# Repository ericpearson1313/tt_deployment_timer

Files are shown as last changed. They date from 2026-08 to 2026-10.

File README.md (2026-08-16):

   

# Tiny Tapeout Verilog Project Template

- [Read the documentation for project](docs/info.md)

## What is Tiny Tapeout?

Tiny Tapeout is an educational project that aims to make it easier and cheaper than ever to get your digital and analog designs manufactured on a real chip.

To learn more and get started, visit https://tinytapeout.com.

## Set up your Verilog project

1. Add your Verilog files to the `src` folder.
2. Edit the [info.yaml](info.yaml) and update information about your project, paying special attention to the `source_files` and `top_module` properties. If you are upgrading an existing Tiny Tapeout project, check out our [online info.yaml migration tool](https://tinytapeout.github.io/tt-yaml-upgrade-tool/).
3. Edit [docs/info.md](docs/info.md) and add a description of your project.
4. Adapt the testbench to your design. See [test/README.md](test/README.md) for more information.

The GitHub action will automatically build the ASIC files using [LibreLane](https://www.zerotoasiccourse.com/terminology/librelane/).

## Enable GitHub actions to build the results page

- [Enabling GitHub Pages](https://tinytapeout.com/faq/#my-github-action-is-failing-on-the-pages-part)

## Resources

- [FAQ](https://tinytapeout.com/faq/)
- [Digital design lessons](https://tinytapeout.com/digital_design/)
- [Learn how semiconductors work](https://tinytapeout.com/siliwiz/)
- [Join the community](https://tinytapeout.com/discord)
- [Build your design locally](https://www.tinytapeout.com/guides/local-hardening/)

## What next?

- [Submit your design to the next shuttle](https://app.tinytapeout.com/).
- Edit [this README](README.md) and explain your design, how it works, and how to test it.
- Share your project on your social network of choice:
  - LinkedIn [#tinytapeout](https://www.linkedin.com/search/results/content/?keywords=%23tinytapeout) [@TinyTapeout](https://www.linkedin.com/company/100708654/)
  - Mastodon [#tinytapeout](https://chaos.social/tags/tinytapeout) [@matthewvenn](https://chaos.social/@matthewvenn)
  - X (formerly Twitter) [#tinytapeout](https://twitter.com/hashtag/tinytapeout) [@tinytapeout](https://twitter.com/tinytapeout)
  - Bluesky [@tinytapeout.com](https://bsky.app/profile/tinytapeout.com)

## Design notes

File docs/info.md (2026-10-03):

<!---

This file is used to generate your project datasheet. Please fill in the information below and delete any unused
sections.

You can also include images in this folder and reference them in the markdown. Each image must be less than
512 kb in size, and the combined size of all images must be less than 1 MB.
-->

## How it works

This TinyTapeout design implements a complete launch‑detect deployment timer (LDT) for model rocket recovery. It polls an external I²C accelerometer, then waits to for a launch accelleration (sustained >2 g), it executes a fixed sequence: a programmable delay, a pre‑charge window, a one‑tick deployment pulse, and follows with a post‑deployment warble tone on a piezo output. Prior to launch continuity checking is done at 1Hz with the piezo giving single beep when ok, and double beep if continuity test failed. Once the launch sequence begins all further inputs are ignored, making the device a single‑shot, deterministic controller that fits comfortably within a 1×1 TinyTapeout tile.

This chip starts with a [datasheet](XS-LDT-01_Datasheet.pdf) where the chip I/O is nailed down and expanded. 

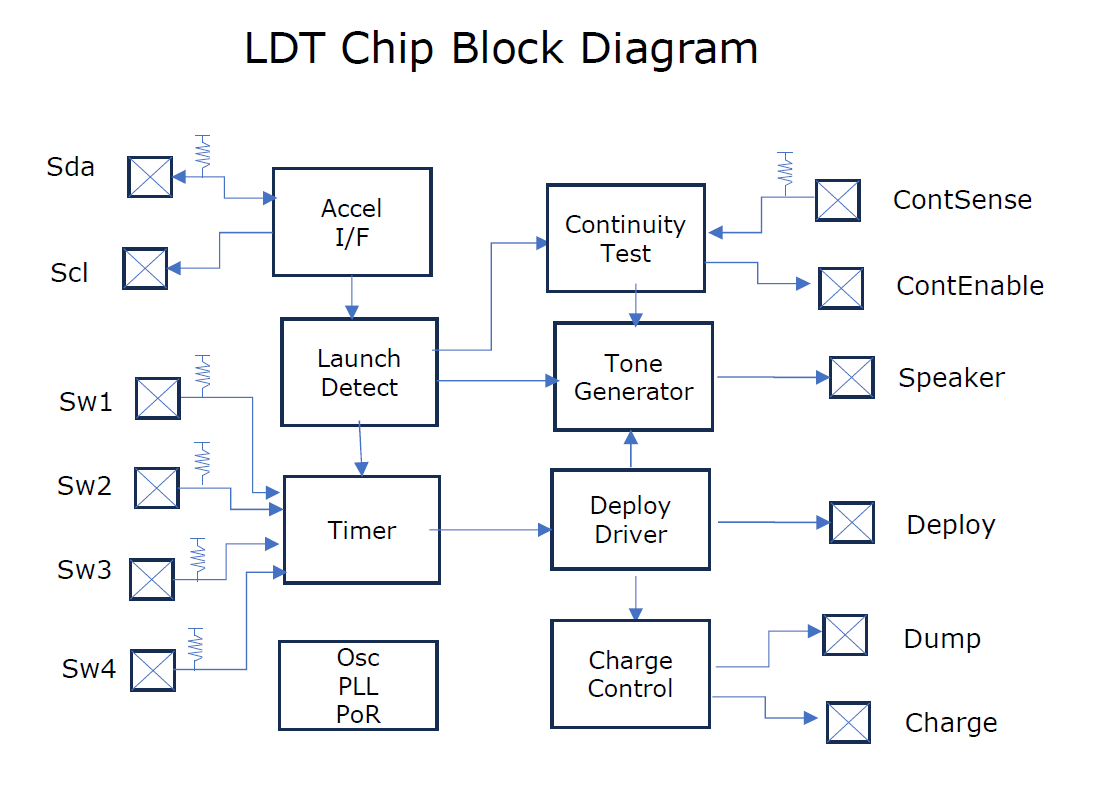
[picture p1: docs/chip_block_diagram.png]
Chip Block Diagram

The I/O is expanded internally into a chip block diagram.

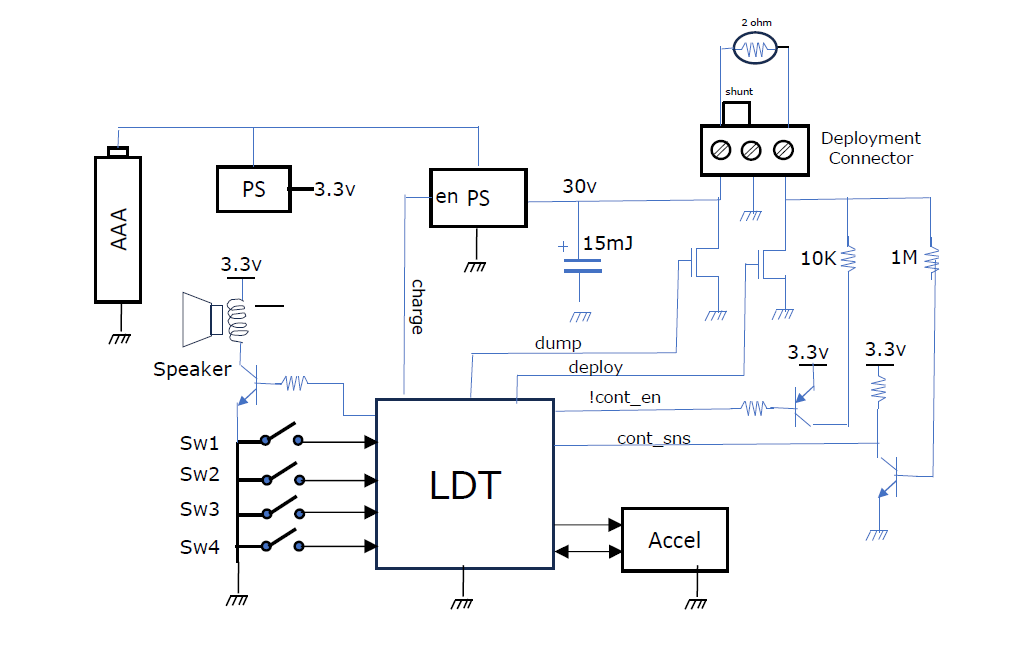
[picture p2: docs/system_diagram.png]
System Diagram

And the I/O is expanded out into the system diagram so the chip context is clear.

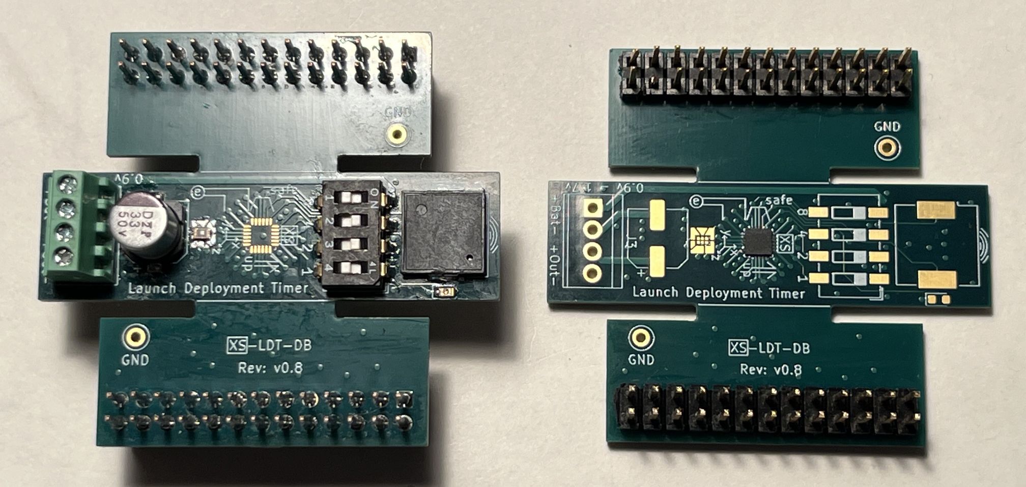
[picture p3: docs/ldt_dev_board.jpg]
LDT Dev Board

Photo of dev board. Left board populated except LDT chip, right with LDT chip (SLG47910V with TT logic). The emulation header breaks out all the chip I/O and allows two boards for testing.

## How to test

A development board was designed, built, and tested. Along with a Max10 I/o Monitoring fpga, the TT pmods can be connected directly
to emulation headers on the development board. Also before endangering the hardware a Max10 chip tester (using the sys model 
used in verificaiton) can be used to test and observe safe reset and operation.

## Verification Summary

This design was validated through a full end‑to‑end pipeline: accelerated RTL simulation (Icarus/Verilator) and gate‑level reset/X‑prop checks; MAX10 FPGA prototyping with real accelerometer and FRAM hardware-in-loop; a flight test with recovered logs that exposed and resolved a periodic write bug; Forge silicon bring‑up using the MAX10 full‑chip emulator and an independent monitor for signal observation; iterative board revisions driven by real hardware behavior; and final OTP, PCB‑level, and system‑level tests confirming correct sequencing, safety behavior, and deployment timing. The commit history captures each stage of this progression, demonstrating repeated, real‑world validation before tapeout

## External hardware

Primary hardware: MXC400 accelerometer by I2C bus, a piezo, Dip_sw4. Two connections to a continuity test circuit and 4 deployment connections.

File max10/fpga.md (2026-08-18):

#### MAX10 FPGA use

A max10 fpga is mounted on a PCB with a emualtor footprint, and HDMI connector.
This fpga is used to bring up a new chip. It provides 4 fold functionallity useful for chip
development, PCB bringup, chip bringup, and manufacturing chip testing.

    - Simulation: Acceleration simulation by combining the Chip, System Simulator, and HDMI Monitor
    - Emulator: Emulate the chip by combining the chip and the HDMI Monitor
    - Monitor: Monitor the pins of a running chip and display on HDMI Monitor (decode ADC, probes)
    - Tester: Test chips by combining a system simulator and HDMI Monitor

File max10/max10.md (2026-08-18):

### Intel/Altera MAX10 

a favourite low cost but capable development fpga. For about $20 gets me a 10M04 with 4K Luts with most-excellent free tools. 
I chose the 144QFP as I can hand solder it, and there is a high density device (for larger builds) the 10M25 which gives me alot of room.
I use the max10 during development in four roles: System Simulation, Emulation, Monitoring, and its used in production for chip Testing.

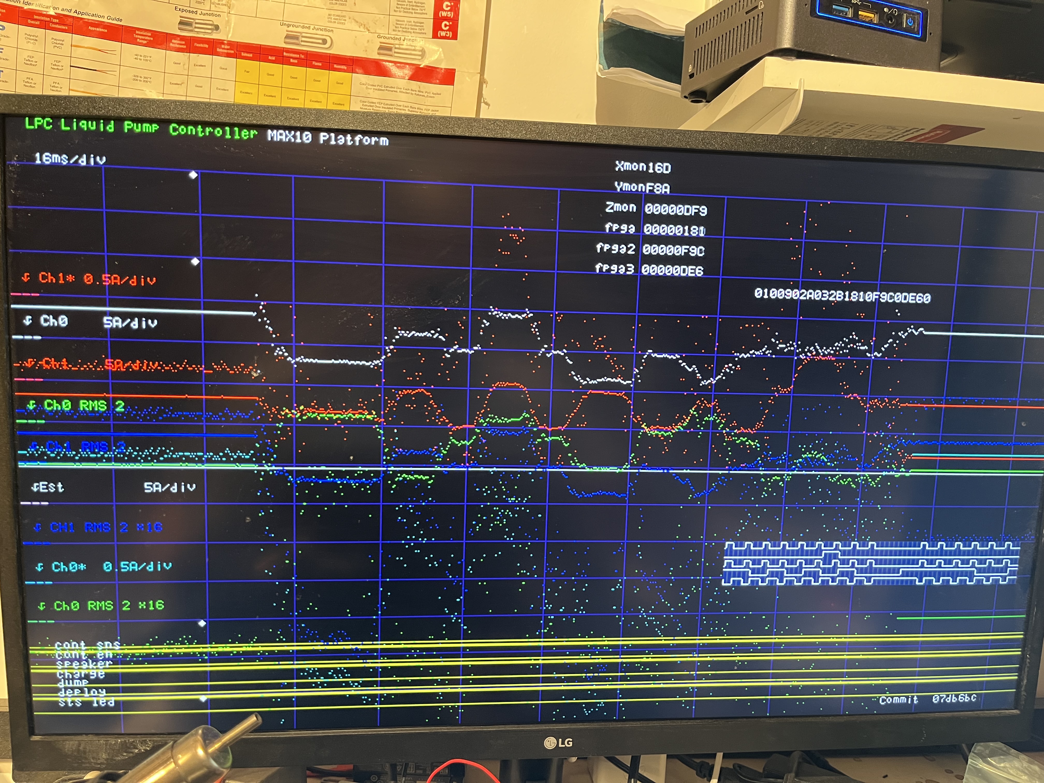
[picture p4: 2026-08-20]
docs/07db6bc.jpeg

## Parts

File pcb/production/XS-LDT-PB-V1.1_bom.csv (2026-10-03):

Designator | Footprint | Quantity | Value | LCSC Part #
C1 | CP_Elec_6.3x7.7 | 1 | UWT1H330MCL1GS | C1864193
C10, C11, C2, C6, C9 | 0603 | 5 | 1u | C15849
C3, C4, C5 | 1206 | 3 | 4.7u | C29823
C7 | 0603 | 1 | 0.1u | C14663
D1 | D_SOD-323F | 1 | MM3Z12 | C19077460
D2 | 0603 | 1 | CD0603-B0340R | C3759853
D3 | 0603 | 1 | LED | C2899911
J3 | TerminalBlock_TE_282834-4_1x04_P2.54mm_Horizontal | 1 | TE_282834-4 | C708735
J4 | CONN_B5B-ZR-SM4-TF_JST | 1 | B5B-ZR-SM4-TF | C265440
L1 | 1210 | 1 | 47uH | C250235
L2 | 1210 | 1 | 4.7uH | C117731
LS1 | Buzzer_CUI_CPT-9019S-SMT | 1 | CUI_CPT-9019S-SMT | C18212234
Q1, Q2 | SOT-23 | 2 | Si2356DS | C5182104
Q3, Q5, Q6 | SOT-23 | 3 | MMBT3904 | C7420353
Q4 | SOT-23 | 1 | SL2319 | C347478
Q7 | SOT-23 | 1 | MMBT3906 | C7420354
Q8 | SOT-23 | 1 | SI2333 | C344008
R10 | 0603 | 1 | 147K | C2998060
R11 | 0603 | 1 | 6K34 | C23087
R12 | 0603 | 1 | 976K | C2933270
R13 | 0603 | 1 | 562K | C2933238
R14, R18, R19, R20, R21, R22, R24, R25 | 0603 | 8 | 10K | C25804
R15, R9 | 0603 | 2 | 3K3 | C22978
R17, R3, R7 | 0603 | 3 | 1M | C22935
R2, R6 | 0603 | 2 | 2K7 | C13167
R26, R8 | 0603 | 2 | 100K | C25803
R4 | 0603 | 1 | 1K | C21190
SW1 | SW_DIP_SPSTx04_Slide_6.7x11.72mm_W6.73mm_P2.54mm_LowProfile_JPin | 1 | CFS-0400TA | C5774648
TP1, TP2, TP3, TP4, TP5 | TestPoint_Pad_D1.0mm | 5 | TestPoint_Small
U1 | QFN-24-3x3mm | 1 | XS-LDT-01
U2 | SOT-23-6 | 1 | MAX5026 | C87603
U3 | MXC4005XC_MEM-M | 1 | MXC4005XC | C404327
U4 | SOT-23-6 | 1 | MCP1640BCH | C478087
U6 | SOT-23-5 | 1 | TLV74311 | C485147
U7 | SOIC-8_3.9x4.9mm_P1.27mm | 1 | FM24W256 | C66020

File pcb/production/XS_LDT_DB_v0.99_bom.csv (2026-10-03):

Designator | Footprint | Quantity | Value | LCSC Part #
C1 | CP_Elec_6.3x7.7 | 1 | 33uF 50v
C10, C11, C2, C6, C9 | 0603 | 5 | 1u | C15849
C3, C4, C5 | 1206 | 3 | 4.7u | C29823
C7, C8 | 0603 | 2 | 0.1u | C14663
D1 | D_SOD-323F | 1 | MM3Z12 | C19077460
D2 | 0603 | 1 | CD0603-B0340R | C3759853
D3 | 0603 | 1 | LED | C2899911
J1, J2 | PinSocket_2x13_P2.54mm_Vertical | 2 | Conn_02x13_Odd_Even
J3 | TerminalBlock_TE_282834-4_1x04_P2.54mm_Horizontal | 1 | Screw_Terminal_01x04
J4 | CONN_B5B-ZR-SM4-TF_JST | 1 | Conn_01x05 | C265440
L1 | 1210 | 1 | 47uH | C250235
L2 | 1210 | 1 | 4.7uH | C117731
LS1 | Buzzer_CUI_CPT-9019S-SMT | 1 | Piezo
Q1, Q2 | SOT-23 | 2 | Si2356DS | C5182104
Q3, Q5, Q6 | SOT-23 | 3 | MMBT3904 | C7420353
Q4 | SOT-23 | 1 | SL2319 | C347478
Q7 | SOT-23 | 1 | MMBT3906 | C7420354
Q8 | SOT-23 | 1 | SI2333 | C2998060
R1 | 0603 | 1 | 0R | C21189
R10 | 0603 | 1 | 147K | C2998060
R11 | 0603 | 1 | 6K34 | C23087
R12 | 0603 | 1 | 976K | C2933270
R13 | 0603 | 1 | 562K | C2933238
R14, R18, R19, R20, R21, R22, R24, R25 | 0603 | 8 | 10K | C25804
R15, R9 | 0603 | 2 | 3K3 | C22978
R16, R23, R5 | 0603 | 3 | dni
R17, R3, R7 | 0603 | 3 | 1M | C22935
R2, R6 | 0603 | 2 | 2K7 | C13167
R26, R8 | 0603 | 2 | 100K | C25803
R4 | 0603 | 1 | 1K | C21190
SW1 | SW_DIP_SPSTx04_Slide_6.7x11.72mm_W6.73mm_P2.54mm_LowProfile_JPin | 1 | SW_DIP_x04
TP1, TP2 | TestPoint_Keystone_5000-5004_Miniature | 2 | GND
U1 | QFN-24-3x3mm | 1 | XS-LDT-01
U2 | SOT-23-6 | 1 | MAX5026 | C87603
U3 | MXC4005XC_MEM-M | 1 | MXC4005XC | C404327
U4 | SOT-23-6 | 1 | MCP1640BCH | C478087
U5 | SOIC-8_3.9x4.9mm_P1.27mm | 1 | AT25xxx
U6 | SOT-23-5 | 1 | TLV74311 | C485147
U7 | SOIC-8_3.9x4.9mm_P1.27mm | 1 | FM24W256 | C66020
U8 | SOT-23 | 1 | LM809
X1 | Oscillator_SMD_Abracon_ASV-4Pin_7.0x5.1mm_HandSoldering | 1 | ASE-48MHz

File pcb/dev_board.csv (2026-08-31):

Reference | Value | Footprint | Datasheet | DPN | Qty
C1 | 33uF 50v | Capacitor_SMD:CP_Elec_6.3x7.7 | https://www.nichicon.co.jp/english/series_items/catalog_pdf/e-uwt.pdf | 493-2224-1-ND | 1
C2, C6, C9, C10 | 1u | Capacitor_SMD:C_0603_1608Metric | ~ | 399-C0603C105K3RAC7867CT-ND | 4
C3-C5 | 4.7u | Capacitor_SMD:C_1206_3216Metric | ~ | 399-C1206C475K5PAC7800CT-ND | 3
C7, C8 | 0.1u | Capacitor_SMD:C_0603_1608Metric | ~ | 399-C0603C104K3RAC7867CT-ND | 2
D2 | CD0603-B0340R | Diode_SMD:D_0603_1608Metric | https://www.digikey.ca/en/products/detail/bourns-inc/CD0603-B0340R/7796828 | CD0603-B0340RCT-ND | 1
D3 | RUN | LED_SMD:LED_0603_1608Metric | https://www.digikey.ca/en/products/detail/kingbright/APTD1608LSYCK/7043071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 | 754-2039-1-ND | 1
J1, J2 | Conn_02x13_Odd_Even | Connector_PinSocket_2.54mm:PinSocket_2x13_P2.54mm_Vertical | https://www.digikey.ca/en/products/detail/samtec-inc/ESQ-113-13-L-D/6693822 | SAM11102-ND | 2
J3 | Screw_Terminal_01x04 | TerminalBlock_TE-Connectivity:TerminalBlock_TE_282834-4_1x04_P2.54mm_Horizontal | https://www.digikey.ca/en/products/detail/w%C3%BCrth-elektronik/691210910004/11477505 | 732-691210910004-ND | 1
J4 | Conn_01x05 | Connector_JST:CONN_B5B-ZR-SM4-TF_JST | https://www.digikey.ca/en/products/detail/jst-sales-america-inc/B5B-ZR-SM4-TF/926591 | 455-1684-1-ND | 1
L1 | 47uH | Inductor_SMD:L_1008_2520Metric | https://www.digikey.ca/en/products/detail/tdk/NLV25T-047J-EF/4741326 | 445-16442-1-ND | 1
L2 | 4.7uH | Inductor_SMD:L_1210_3225Metric | https://www.digikey.ca/en/products/detail/taiyo-yuden/CBC3225T4R7MR/958015 | 587-1624-1-ND | 1
LS1 | Piezo | Buzzer_Beeper:Buzzer_CUI_CPT-9019S-SMT | https://www.digikey.ca/en/products/detail/same-sky-formerly-cui-devices/CPT-9019A-SMT-TR/19105220 | 2223-CPT-9019A-SMT-TRCT-ND | 1
Q1, Q2 | Si2356DS | Package_TO_SOT_SMD:SOT-23 | https://www.vishay.com/docs/62893/si2356ds.pdf | SI2356DS-T1-GE3CT-ND | 2
Q6 | MMBT3904 | Package_TO_SOT_SMD:SOT-23 | https://www.digikey.ca/en/products/detail/diotec-semiconductor/MMBT3904/13163698 | 4878-MMBT3904CT-ND | 1
Q7 | MMBT3906 | Package_TO_SOT_SMD:SOT-23 | https://www.digikey.ca/en/products/detail/diotec-semiconductor/MMBT3906/13163222 | 4878-MMBT3906CT-ND | 1
R1 | 0R | Resistor_SMD:R_0603_1608Metric |  | P0.0GCT-ND | 1
R2, R6, R9, R15 | 3K3 | Resistor_SMD:R_0603_1608Metric |  | 311-3.30KHRCT-ND | 4
R3, R8, R14 | 10K | Resistor_SMD:R_0603_1608Metric |  | P10.0KHCT-ND | 3
R4 | 1K | Resistor_SMD:R_0603_1608Metric |  | 541-1.00KHCT-ND | 1
R5, R16, R23 | dni | Resistor_SMD:R_0603_1608Metric |  | ~ | 3
R7 | 100K | Resistor_SMD:R_0603_1608Metric |  | P100KHCT-ND | 1
R10 | 147K | Resistor_SMD:R_0603_1608Metric |  | P147KHCT-ND | 1
R11 | 6K34 | Resistor_SMD:R_0603_1608Metric |  | P6.34KHCT-ND | 1
R12 | 976K | Resistor_SMD:R_0603_1608Metric |  | P976KHCT-ND | 1
R13 | 562K | Resistor_SMD:R_0603_1608Metric |  | P562KHCT-ND | 1
SW1 | SW_DIP_x04 | Button_Switch_SMD:SW_DIP_SPSTx04_Slide_6.7x11.72mm_W6.73mm_P2.54mm_LowProfile_JPin | https://www.digikey.ca/en/products/detail/nidec-components/CFS-0400TA/12142605 | 563-CFS-0400TACT-ND | 1
TP1, TP2 | GND | TestPoint:TestPoint_Keystone_5000-5004_Miniature | https://www.digikey.ca/en/products/detail/keystone-electronics/1037/315153 | 36-1037-ND | 2
U1 | XS-LDT-01 | myspace pcb:QFN-24-3x3mm | https://github.com/ericpearson1313/tt_pump_out_chip | ~ | 1
U2 | MAX5026 | Package_TO_SOT_SMD:SOT-23-6 | https://www.analog.com/media/en/technical-documentation/data-sheets/MAX5025-MAX5028.pdf | MAX5026EUT+TCT-ND | 1
U3 | MXC4005XC | Sensor:MXC4005XC_MEM-M | https://mm.digikey.com/Volume0/opasdata/d220001/medias/docus/323/MXC400xXC_Rev.B_4-24-15.pdf | 1267-1075-1-ND | 1
U4 | MCP1640BCH | Package_TO_SOT_SMD:SOT-23-6 | https://www.digikey.ca/en/products/detail/microchip-technology/MCP1640BT-I-CHY/2258563 | MCP1640BT-I/CHYCT-ND | 1
U5 | AT25xxx | Package_SO:SOIC-8_3.9x4.9mm_P1.27mm | https://www.renesas.com/en/document/dst/at25eu0011a-datasheet?r=1608521 | 1695-AT25EU0011A-SSHN-TCT-ND | 1
U6 | TLV74311 | Package_TO_SOT_SMD:SOT-23-5 | https://www.digikey.ca/en/products/detail/texas-instruments/TLV74311PDBVR/7593919 | 296-50002-1-ND | 1
U7 | FM24W256 | Package_SO:SOIC-8_3.9x4.9mm_P1.27mm | https://www.digikey.ca/en/products/detail/infineon-technologies/FM24W256-GTR/3788943 | 448-FM24W256-GTRCT-ND | 1
U8 | LM809 | Package_TO_SOT_SMD:SOT-23 | http://www.ti.com/lit/ds/symlink/lm809.pdf | LM809M3-2.63/NOPBCT-ND | 1
X1 | ASE-48MHz | Oscillator:Oscillator_SMD_Abracon_ASV-4Pin_7.0x5.1mm_HandSoldering | http://www.abracon.com/Oscillators/ASV.pdf | 535-9328-1-ND | 1

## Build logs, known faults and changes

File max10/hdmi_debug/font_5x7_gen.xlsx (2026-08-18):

8'h41,8'h42,8'h43,8'h44,8'h45,8'h46,8'h47,8'h48,8'h49,8'h4A, | A |  |  |  |  | 8'h41, | B |  |  |  |  | 8'h42, | C |  |  |  |  | 8'h43, | D |  |  |  |  | 8'h44, | E |  |  |  |  | 8'h45, | F |  |  |  |  | 8'h46, | G |  |  |  |  | 8'h47, | H |  |  |  |  | 8'h48, | I |  |  |  |  | 8'h49, | J
01110_11110_01110_11110_11111_11111_01110_10001_01110_00001_ |  | 1 | 1 | 1 |  | 01110_ | 1 | 1 | 1 | 1 |  | 11110_ |  | 1 | 1 | 1 |  | 01110_ | 1 | 1 | 1 | 1 |  | 11110_ | 1 | 1 | 1 | 1 | 1 | 11111_ | 1 | 1 | 1 | 1 | 1 | 11111_ |  | 1 | 1 | 1 |  | 01110_ | 1 |  |  |  | 1 | 10001_ |  | 1 | 1 | 1 |  | 01110_
10001_10001_10001_10001_10000_10000_10001_10001_00100_00001_ | 1 |  |  |  | 1 | 10001_ | 1 |  |  |  | 1 | 10001_ | 1 |  |  |  | 1 | 10001_ | 1 |  |  |  | 1 | 10001_ | 1 |  |  |  |  | 10000_ | 1 |  |  |  |  | 10000_ | 1 |  |  |  | 1 | 10001_ | 1 |  |  |  | 1 | 10001_ |  |  | 1 |  |  | 00100_
10001_10001_10000_10001_10000_10000_10000_10001_00100_00001_ | 1 |  |  |  | 1 | 10001_ | 1 |  |  |  | 1 | 10001_ | 1 |  |  |  |  | 10000_ | 1 |  |  |  | 1 | 10001_ | 1 |  |  |  |  | 10000_ | 1 |  |  |  |  | 10000_ | 1 |  |  |  |  | 10000_ | 1 |  |  |  | 1 | 10001_ |  |  | 1 |  |  | 00100_
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

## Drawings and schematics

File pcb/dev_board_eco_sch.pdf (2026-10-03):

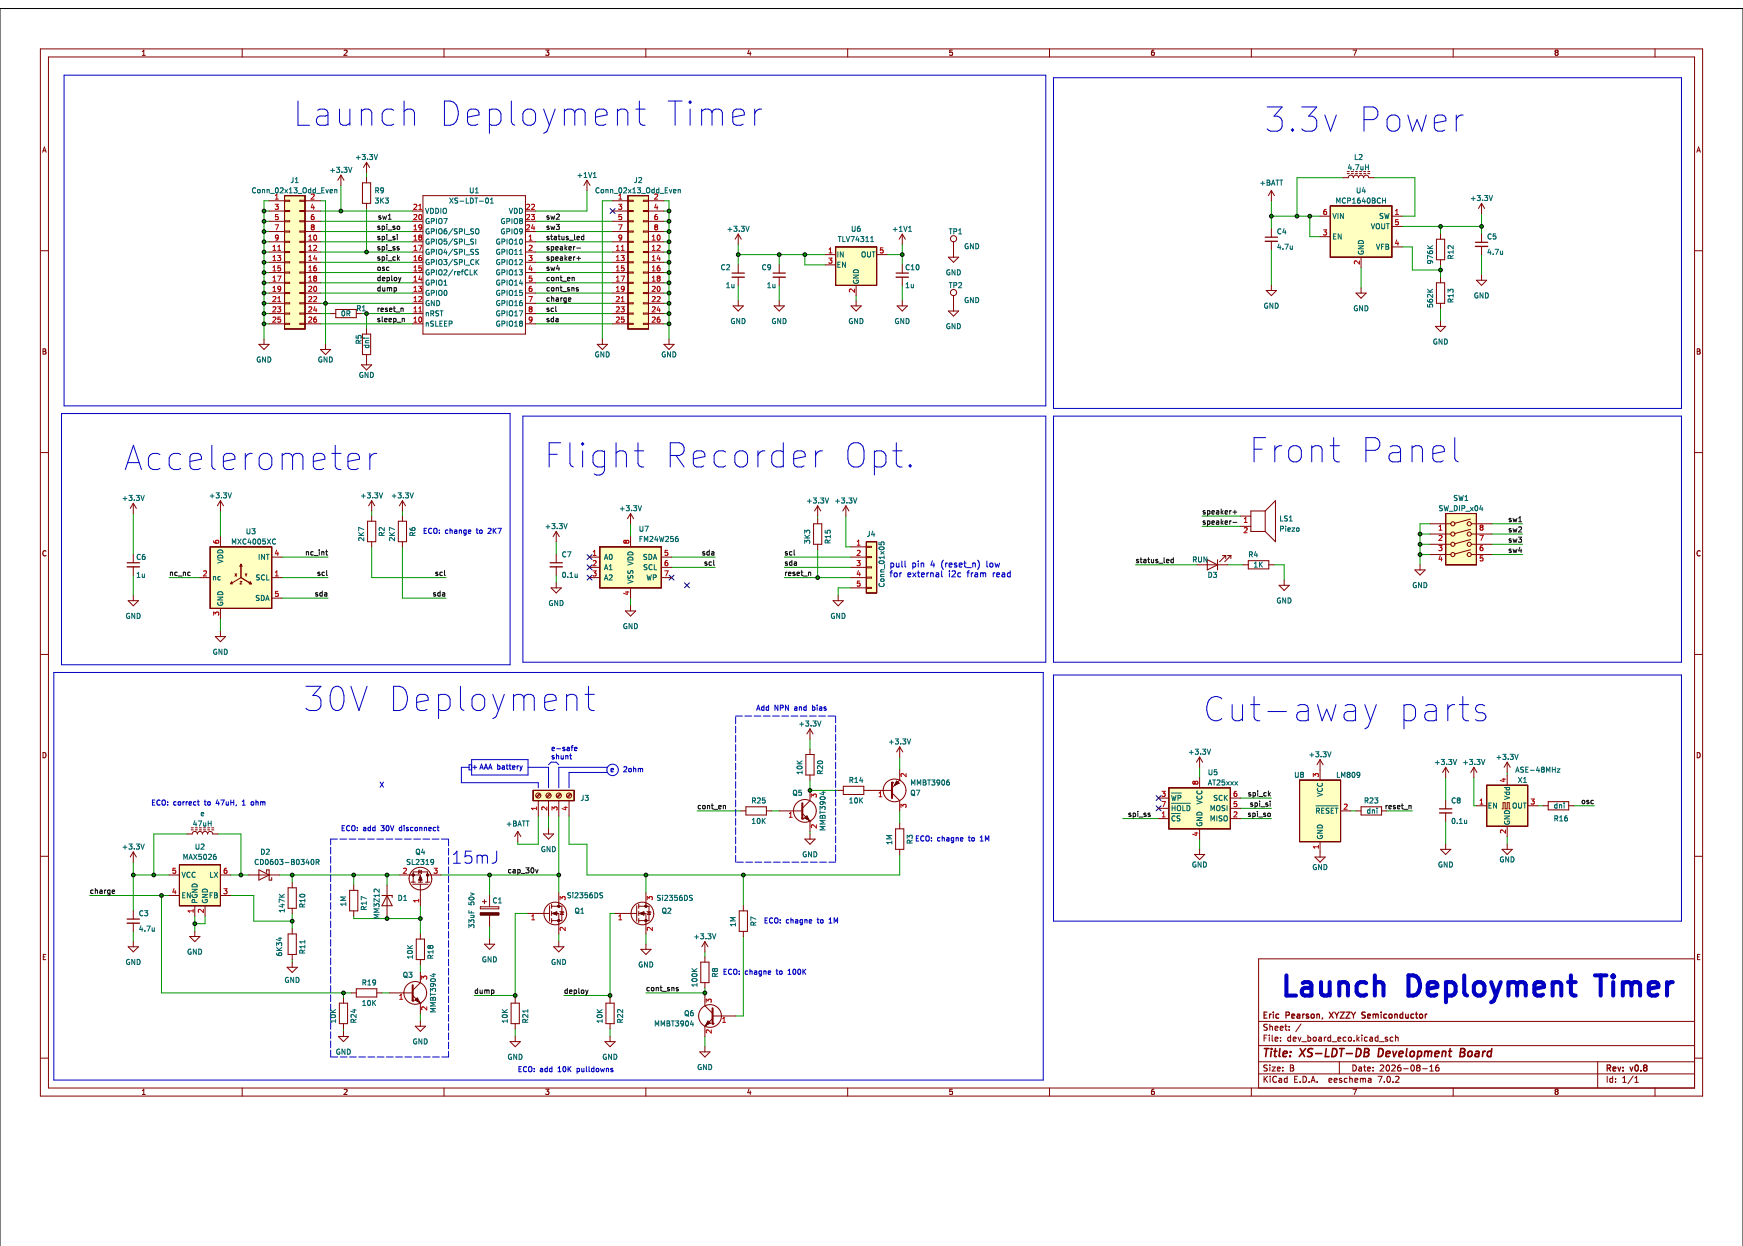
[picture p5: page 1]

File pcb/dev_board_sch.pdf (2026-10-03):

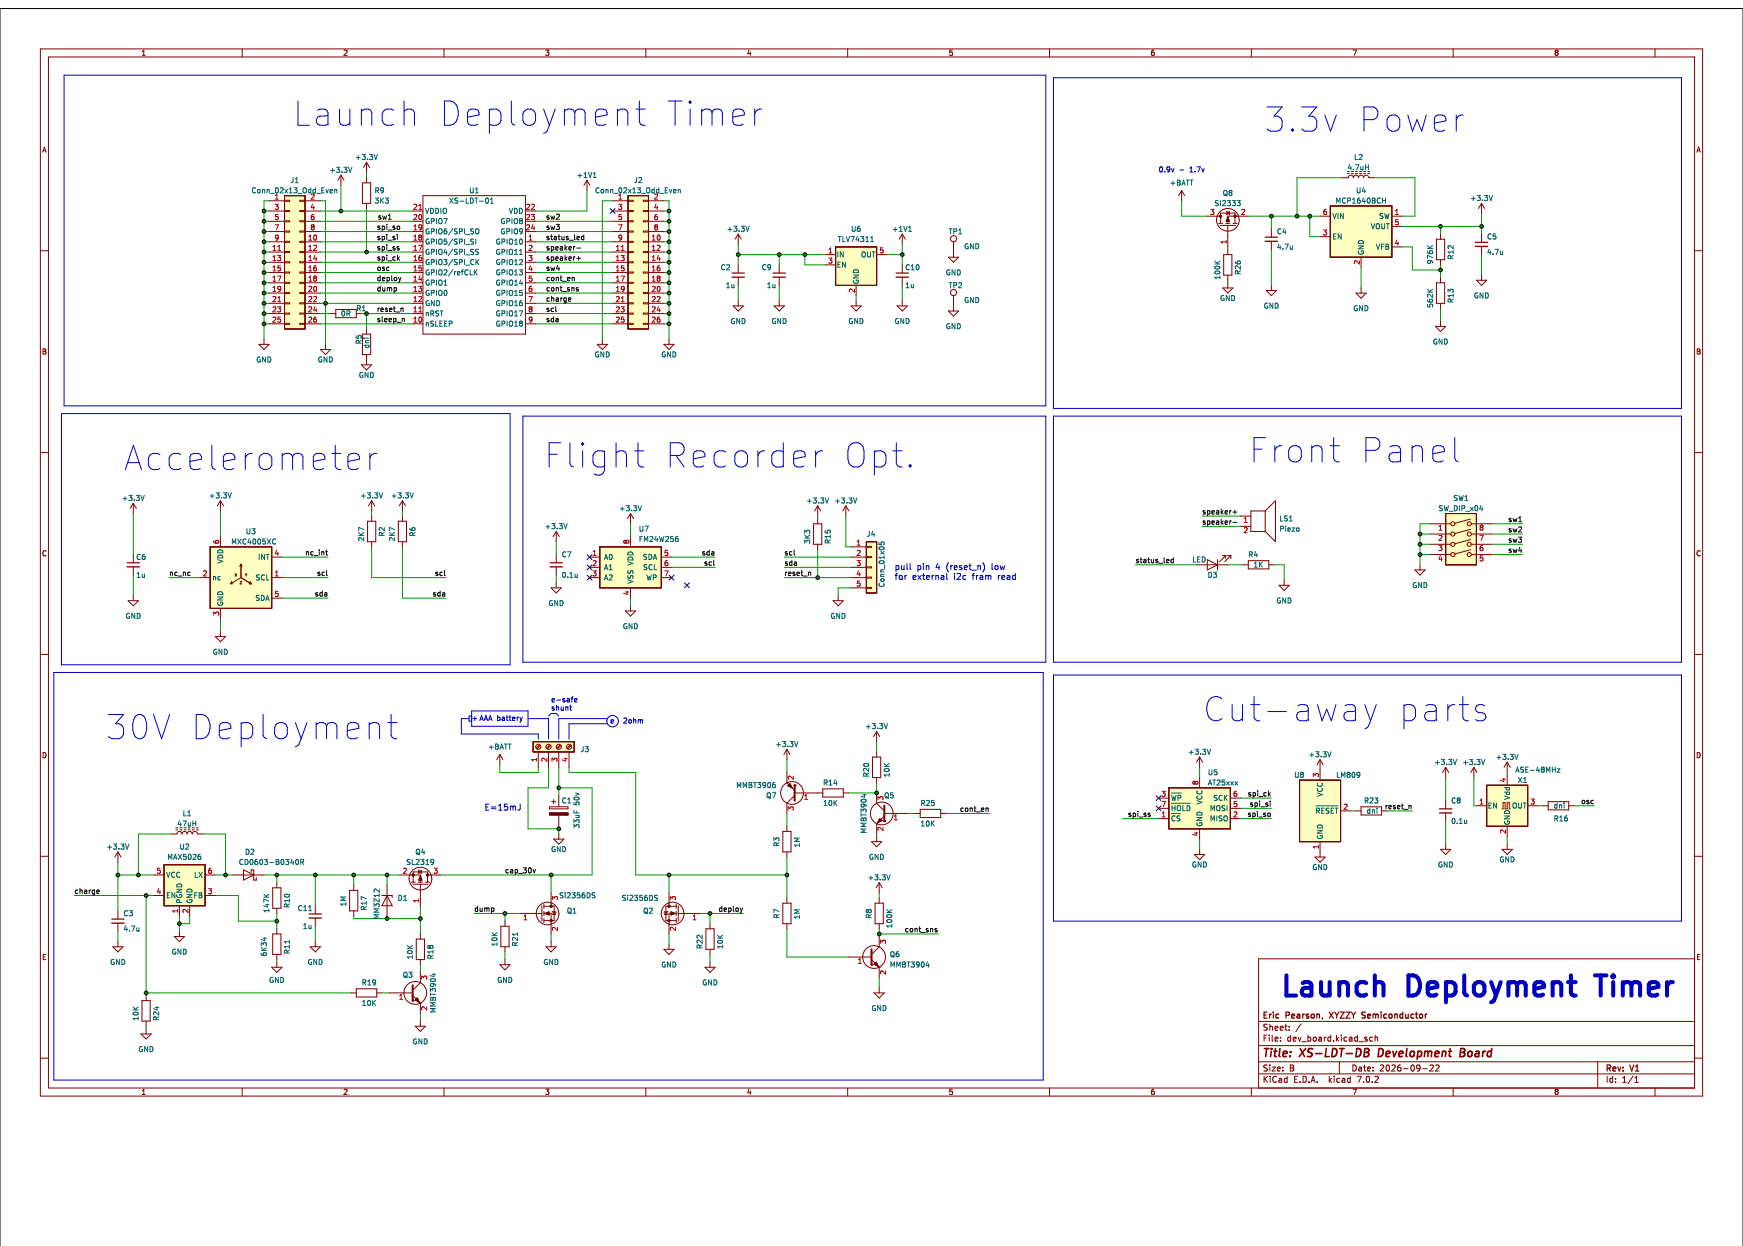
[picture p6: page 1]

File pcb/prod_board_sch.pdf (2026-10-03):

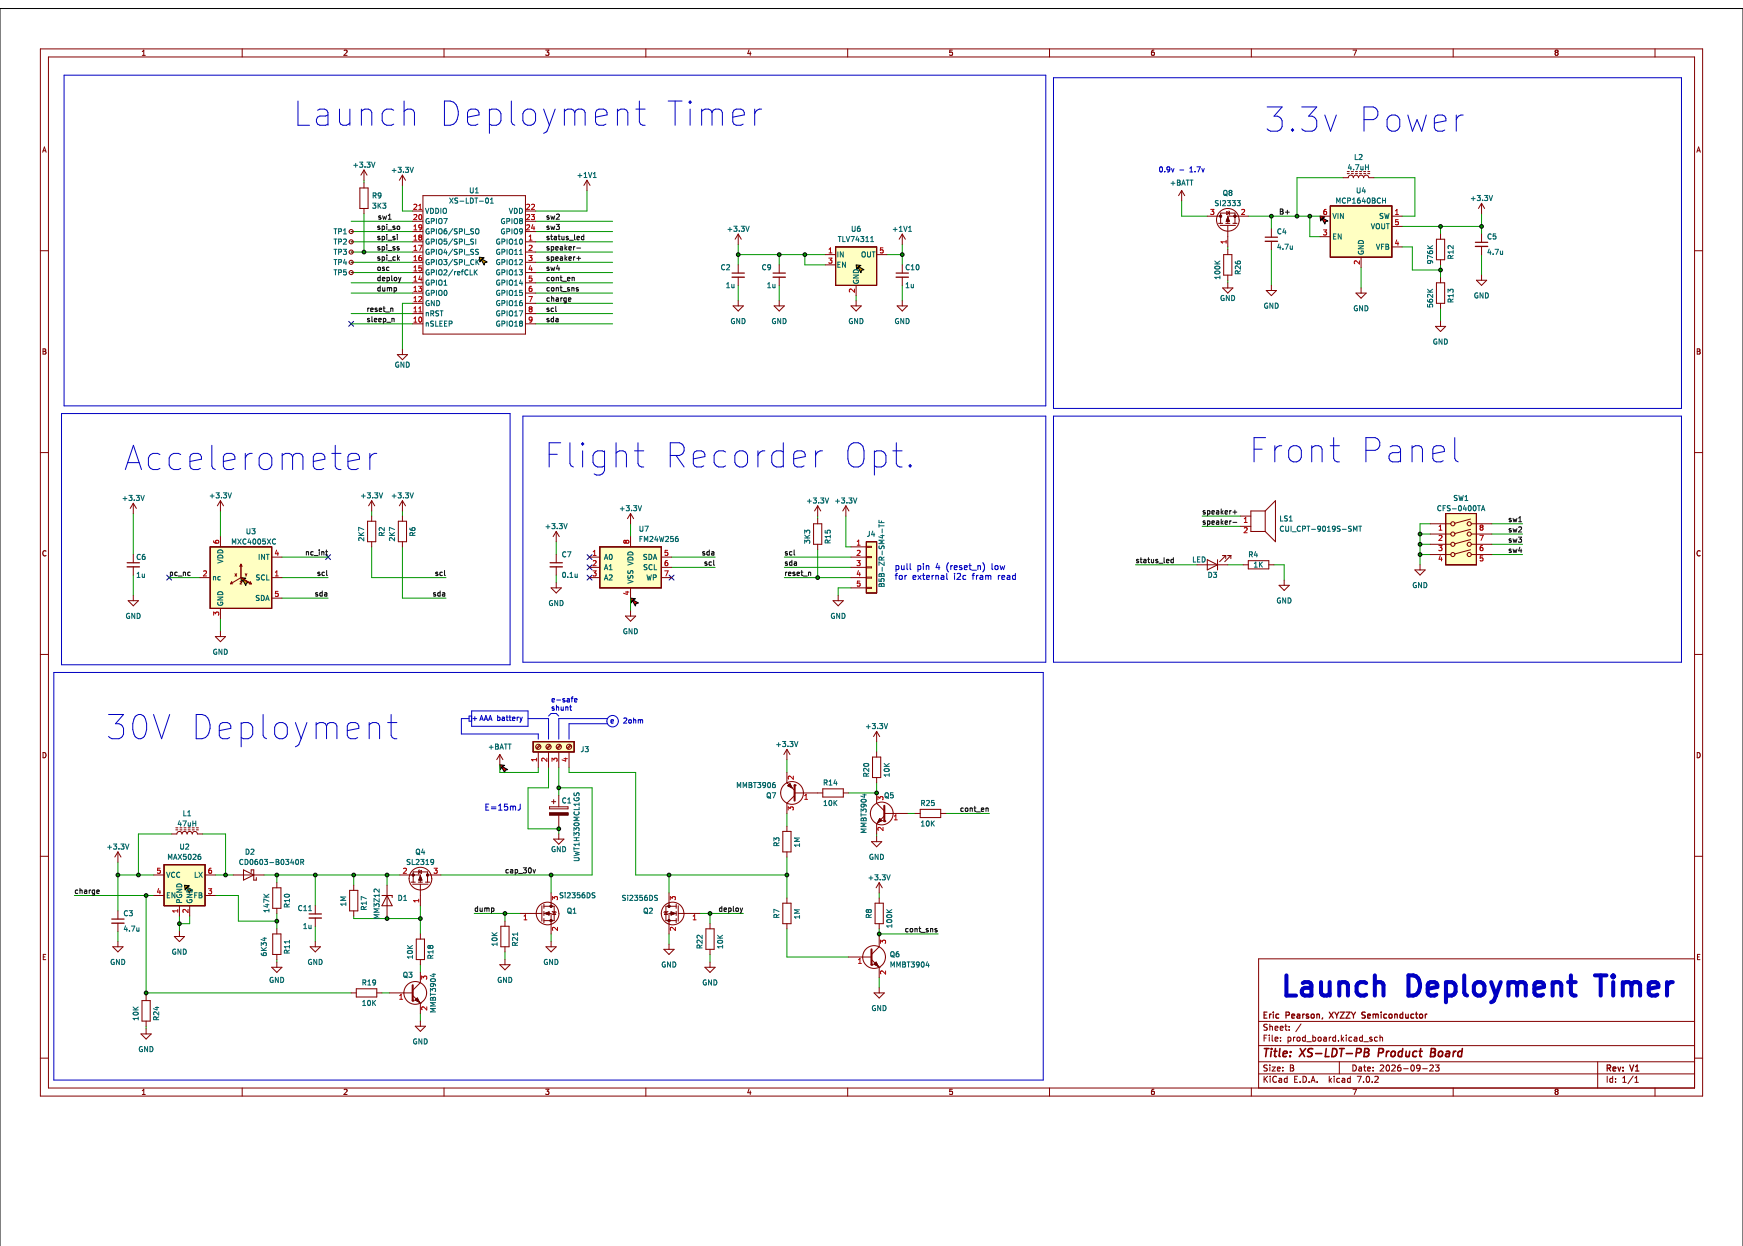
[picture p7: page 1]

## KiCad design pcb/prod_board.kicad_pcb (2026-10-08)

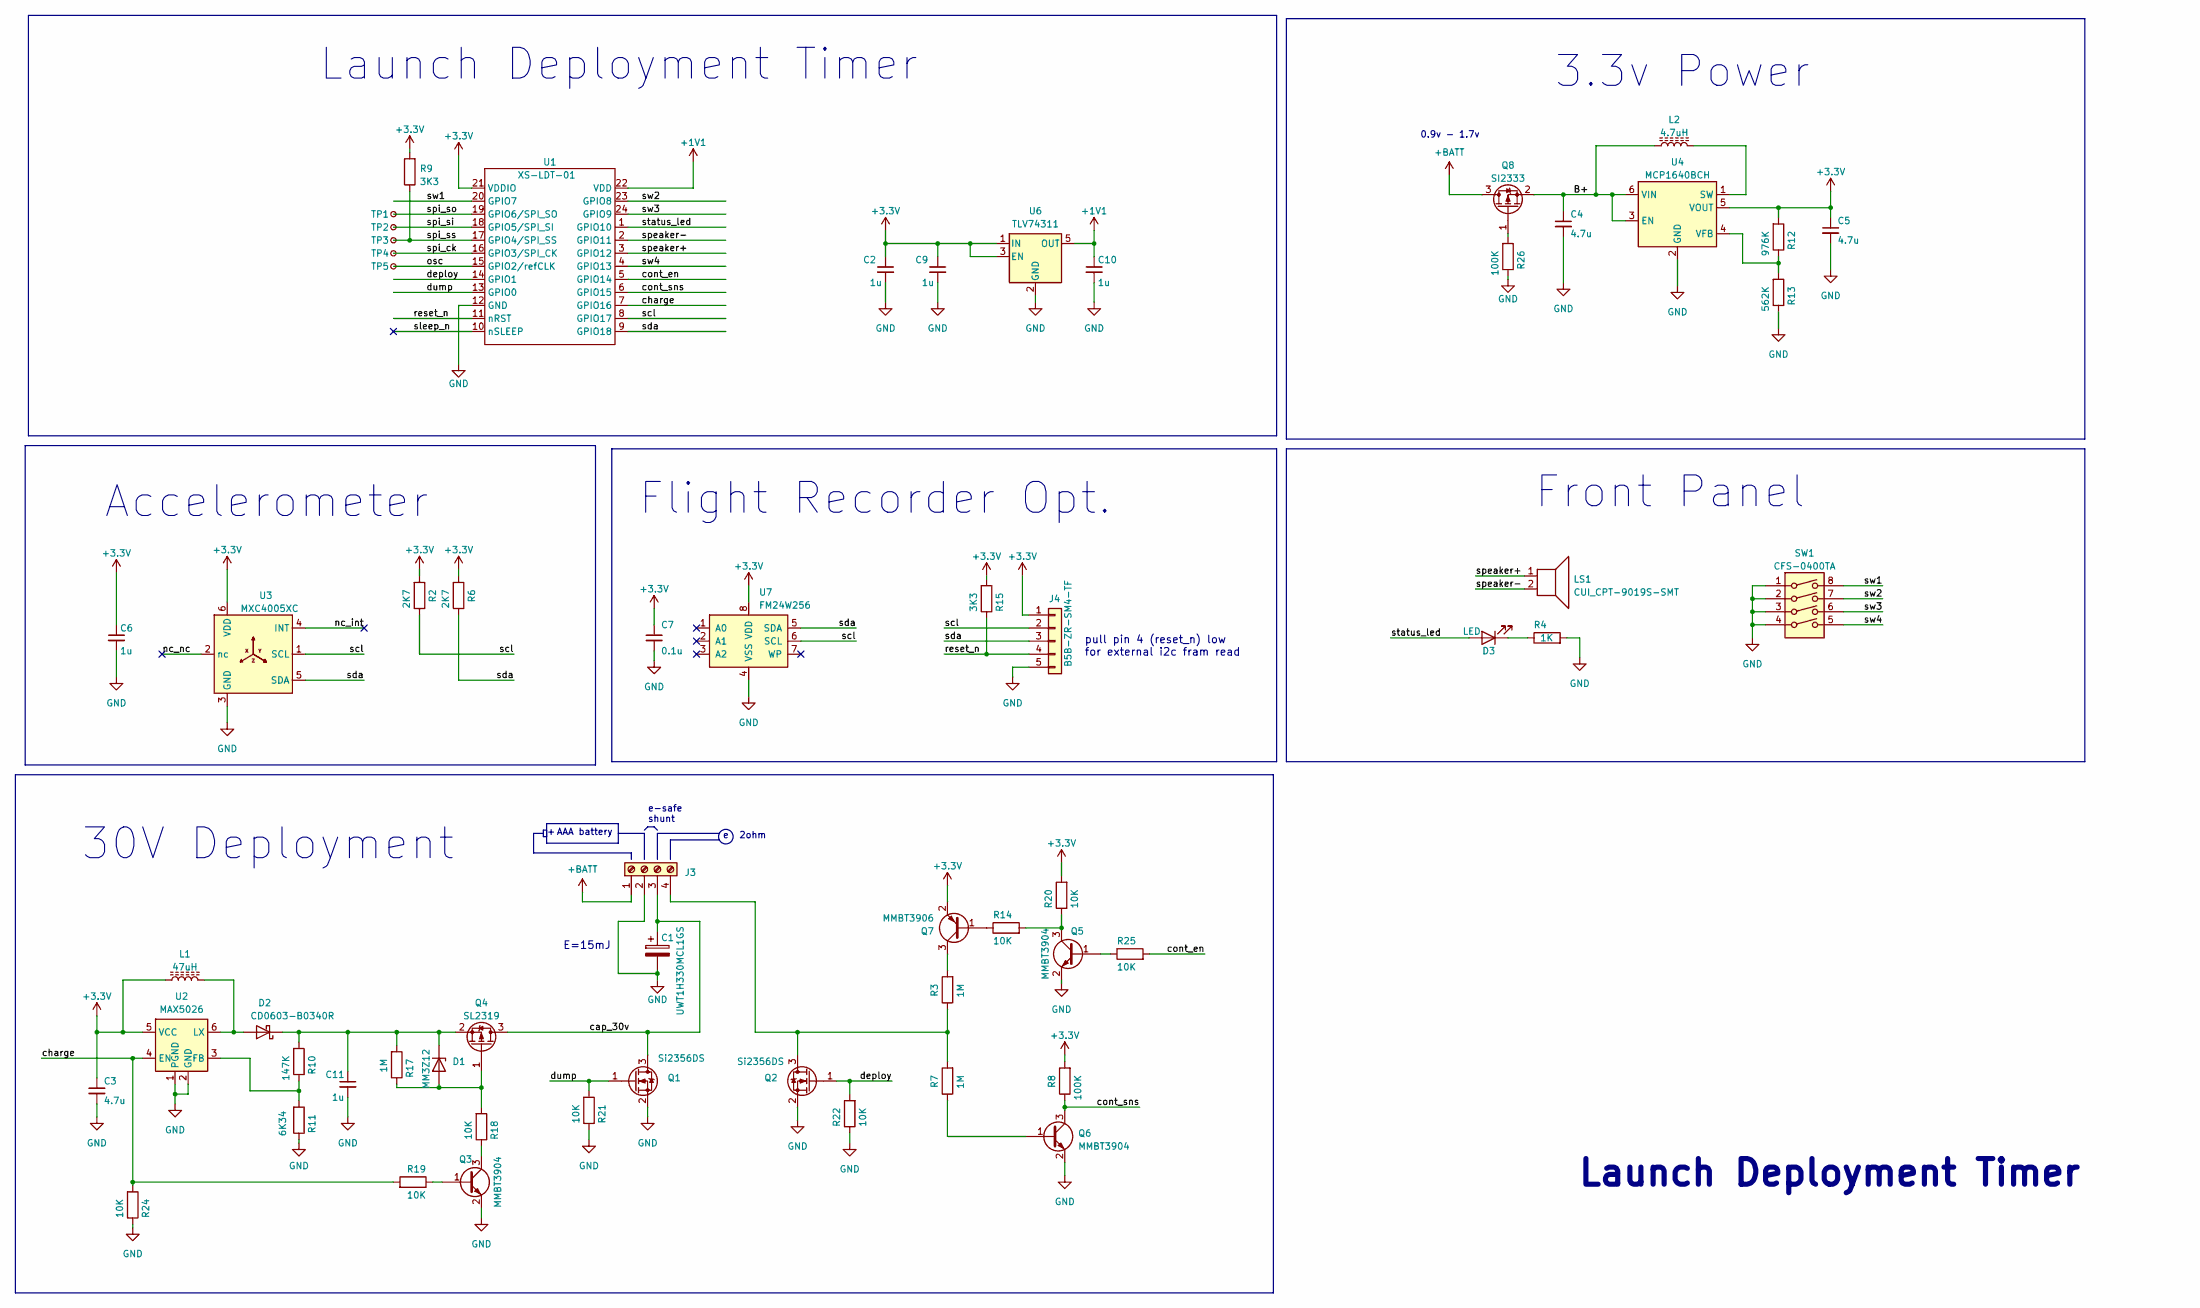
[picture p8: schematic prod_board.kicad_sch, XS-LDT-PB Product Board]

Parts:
C1: UWT1H330MCL1GS; CP_Elec_6.3x7.7; LCSC PN C1864193
C2, C6, C9, C10, C11: 1u; C_0603_1608Metric; LCSC PN C15849
C3, C4, C5: 4.7u; C_1206_3216Metric; LCSC PN C29823
C7: 0.1u; C_0603_1608Metric; LCSC PN C14663
D1: MM3Z12; D_SOD-323F; LCSC PN C19077460
D2: CD0603-B0340R; D_0603_1608Metric; LCSC PN C3759853
D3: LED; LED_0603_1608Metric; LCSC PN C2899911
J3: TE_282834-4; TerminalBlock_TE_282834-4_1x04_P2.54mm_Horizontal; LCSC PN C708735
J4: B5B-ZR-SM4-TF; CONN_B5B-ZR-SM4-TF_JST; LCSC PN C265440
L1: 47uH; L_1210_3225Metric; LCSC PN C250235
L2: 4.7uH; L_1210_3225Metric; LCSC PN C117731
LS1: CUI_CPT-9019S-SMT; Buzzer_CUI_CPT-9019S-SMT; LCSC PN C18212234
Q1, Q2: Si2356DS; SOT-23; LCSC PN C5182104
Q3, Q5, Q6: MMBT3904; SOT-23; LCSC PN C7420353
Q4: SL2319; SOT-23; LCSC PN C347478
Q7: MMBT3906; SOT-23; LCSC PN C7420354
Q8: SI2333; SOT-23; LCSC PN C344008
R2, R6: 2K7; R_0603_1608Metric; LCSC PN C13167
R3, R7, R17: 1M; R_0603_1608Metric; LCSC PN C22935
R4: 1K; R_0603_1608Metric; LCSC PN C21190
R8, R26: 100K; R_0603_1608Metric; LCSC PN C25803
R9, R15: 3K3; R_0603_1608Metric; LCSC PN C22978
R10: 147K; R_0603_1608Metric; LCSC PN C2998060
R11: 6K34; R_0603_1608Metric; LCSC PN C23087
R12: 976K; R_0603_1608Metric; LCSC PN C2933270
R13: 562K; R_0603_1608Metric; LCSC PN C2933238
R14, R18, R19, R20, R21, R22, R24, R25: 10K; R_0603_1608Metric; LCSC PN C25804
SW1: CFS-0400TA; SW_DIP_SPSTx04_Slide_6.7x11.72mm_W6.73mm_P2.54mm_LowProfile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; LCSC PN C5774648
TP1, TP2, TP3, TP4, TP5: TestPoint_Small; TestPoint_Pad_D1.0mm
U1: XS-LDT-01; QFN-24-3x3mm
U2: MAX5026; SOT-23-6; LCSC PN C87603
U3: MXC4005XC; MXC4005XC_MEM-M; LCSC PN C404327
U4: MCP1640BCH; SOT-23-6; LCSC PN C478087
U6: TLV74311; SOT-23-5; LCSC PN C485147
U7: FM24W256; SOIC-8_3.9x4.9mm_P1.27mm; LCSC PN C66020

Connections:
+1V1: C10.1, U1.22 (VDD), U6.5 (OUT)
+3.3V: C2.1, C3.1, C5.1, C6.1, C7.1, C9.1, J4.1, L1.1, Q7.2 (E), R2.2, R6.2, R8.2, R9.2, R12.2, R15.2, R20.2, U1.21 (VDDIO), U2.5 (VCC), U3.6 (VDD), U4.5 (VOUT), U6.1 (IN), U6.3 (EN), U7.8 (VDD)
+BATT: J3.1, Q8.3 (D)
/B+: C4.1, L2.1, Q8.2 (S), U4.3 (EN), U4.6 (VIN)
/cap_30v: C1.1, J3.3, Q1.3 (D), Q4.3 (D)
/charge: R19.2, R24.2, U1.7 (GPIO16), U2.4 (EN)
/cont_en: R25.2, U1.5 (GPIO14)
/cont_sns: Q6.3 (C), R8.1, U1.6 (GPIO15)
/deploy: Q2.1 (G), R22.2, U1.14 (GPIO1)
/dump: Q1.1 (G), R21.2, U1.13 (GPIO0)
/nc_int: U3.4 (INT)
/nc_nc: U3.2 (nc)
/osc: TP5.1, U1.15 (GPIO2/refCLK)
/reset_n: J4.4, R15.1, U1.11 (nRST)
/scl: J4.2, R2.1, U1.8 (GPIO17), U3.1 (SCL), U7.6 (SCL)
/sda: J4.3, R6.1, U1.9 (GPIO18), U3.5 (SDA), U7.5 (SDA)
/sleep_n: U1.10 (nSLEEP)
/speaker+: LS1.1, U1.3 (GPIO12)
/speaker-: LS1.2, U1.2 (GPIO11)
/spi_ck: TP4.1, U1.16 (GPIO3/SPI_CK)
/spi_si: TP2.1, U1.18 (GPIO5/SPI_SI)
/spi_so: TP1.1, U1.19 (GPIO6/SPI_SO)
/spi_ss: R9.1, TP3.1, U1.17 (GPIO4/SPI_SS)
/status_led: D3.2 (A), U1.1 (GPIO10)
/sw1: SW1.8, U1.20 (GPIO7)
/sw2: SW1.7, U1.23 (GPIO8)
/sw3: SW1.6, U1.24 (GPIO9)
/sw4: SW1.5, U1.4 (GPIO13)
GND: C1.2, C2.2, C3.2, C4.2, C5.2, C6.2, C7.2, C9.2, C10.2, C11.2, J3.2, J4.5, Q1.2 (S), Q2.2 (S), Q3.2 (E), Q5.2 (E), Q6.2 (E), R4.2, R11.1, R13.1, R21.1, R22.1, R24.1, R26.1, SW1.1, SW1.2, SW1.3, SW1.4, U1.12 (GND), U2.1 (PGND), U2.2 (GND), U3.3 (GND), U4.2 (GND), U6.2 (GND), U7.4 (VSS)
unnamed: D1.2 (A), Q4.1 (G), R17.1, R18.2
unnamed: C11.1, D1.1 (K), D2.1 (K), Q4.2 (S), R10.2, R17.2
unnamed: D2.2 (A), L1.2, U2.6 (LX)
unnamed: D3.1 (K), R4.1
unnamed: J3.4, Q2.3 (D), R3.1, R7.2
unnamed: Q3.1 (B), R19.1
unnamed: Q3.3 (C), R18.1
unnamed: Q5.1 (B), R25.1
unnamed: Q5.3 (C), R14.2, R20.1
unnamed: Q6.1 (B), R7.1
unnamed: Q7.1 (B), R14.1
unnamed: Q7.3 (C), R3.2
unnamed: Q8.1 (G), R26.2
unnamed: R10.1, R11.2, U2.3 (FB)
unnamed: L2.2, U4.1 (SW)
unnamed: R12.1, R13.2, U4.4 (VFB)

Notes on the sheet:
Accelerometer
Front Panel
Launch Deployment Timer
Launch Deployment Timer
2ohm
0.9v - 1.7v
3.3v Power
Flight Recorder Opt.
E=15mJ
pull pin 4 (reset_n) low for external i2c fram read
e-safe shunt
30V Deployment
AAA battery

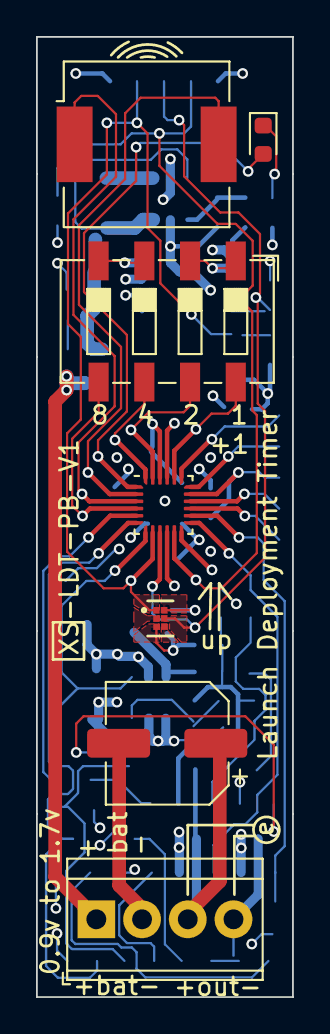
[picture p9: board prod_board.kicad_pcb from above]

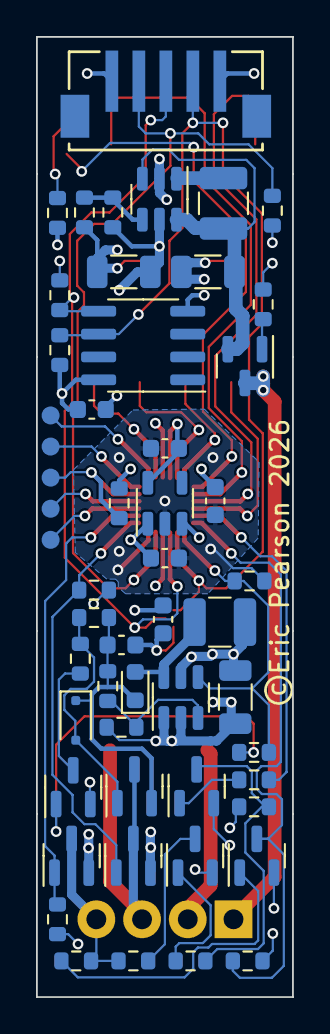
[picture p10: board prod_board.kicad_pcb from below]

Board: 4 copper layers, 14.2 x 53.3 mm, 60 parts (53 on the bottom side), 42 nets.

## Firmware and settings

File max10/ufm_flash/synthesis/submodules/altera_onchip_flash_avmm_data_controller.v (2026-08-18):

// (C) 2001-2024 Intel Corporation. All rights reserved.
// Your use of Intel Corporation's design tools, logic functions and other 
// software and tools, and its AMPP partner logic functions, and any output 
// files from any of the foregoing (including device programming or simulation 
// files), and any associated documentation or information are expressly subject 
// to the terms and conditions of the Intel Program License Subscription 
// Agreement, Intel FPGA IP License Agreement, or other applicable 
// license agreement, including, without limitation, that your use is for the 
// sole purpose of programming logic devices manufactured by Intel and sold by 
// Intel or its authorized distributors.  Please refer to the applicable 
// agreement for further details.


////////////////////////////////////////////////////////////////////
//
//  ALTERA_ONCHIP_FLASH_AVMM_DATA_CONTROLLER (SERIAL-to-SERIAL MODE)
//
//  Copyright (C) 1991-2013 Altera Corporation
//  Your use of Altera Corporation's design tools, logic functions 
//  and other software and tools, and its AMPP partner logic 
//  functions, and any output files from any of the foregoing 
//  (including device programming or simulation files), and any 
//  associated documentation or information are expressly subject 
//  to the terms and conditions of the Altera Program License 
//  Subscription Agreement, Altera MegaCore Function License 
//  Agreement, or other applicable license agreement, including, 
//  without limitation, that your use is for the sole purpose of 
//  programming logic devices manufactured by Altera and sold by 
//  Altera or its authorized distributors.  Please refer to the 
//  applicable agreement for further details.
//
////////////////////////////////////////////////////////////////////

// synthesis VERILOG_INPUT_VERSION VERILOG_2001

`timescale 1 ps / 1 ps

module altera_onchip_flash_avmm_data_controller (
    // To/From System
    clock,
    reset_n,
    
    // To/From Flash IP interface
    flash_busy,
    flash_se_pass,
    flash_sp_pass,
    flash_osc,
    flash_drdout,
    flash_xe_ye,
    flash_se,
    flash_arclk,
    flash_arshft,
    flash_drclk,
    flash_drshft,
    flash_drdin,
    flash_nprogram,
    flash_nerase,
    flash_ardin,
        
    // To/From Avalon_MM data slave interface
    avmm_read,
    avmm_write,
    avmm_addr,
    avmm_writedata,
    avmm_burstcount,
    avmm_waitrequest,
    avmm_readdatavalid,
    avmm_readdata,
        
    // To/From Avalon_MM csr slave interface
    csr_control,
    csr_status
);

    parameter READ_AND_WRITE_MODE = 0;
    parameter WRAPPING_BURST_MODE = 0;
    parameter DATA_WIDTH = 32;
    parameter AVMM_DATA_ADDR_WIDTH = 20;
    parameter AVMM_DATA_BURSTCOUNT_WIDTH = 4;
    parameter FLASH_ADDR_WIDTH = 23;
    parameter FLASH_SEQ_READ_DATA_COUNT = 2;    //number of 32-bit data per sequential read
    parameter FLASH_READ_CYCLE_MAX_INDEX = 3;    //period to for each sequential read
    parameter FLASH_ADDR_ALIGNMENT_BITS = 1;     //number of last addr bits for alignment
    parameter FLASH_RESET_CYCLE_MAX_INDEX = 28;    //period that required by flash before back to idle for erase and program operation
    parameter FLASH_BUSY_TIMEOUT_CYCLE_MAX_INDEX = 112; //flash busy timeout period (960ns)
    parameter FLASH_ERASE_TIMEOUT_CYCLE_MAX_INDEX = 40603248; //erase timeout period (350ms)
    parameter FLASH_WRITE_TIMEOUT_CYCLE_MAX_INDEX = 35382; //write timeout period (305us)
    parameter MIN_VALID_ADDR = 1;
    parameter MAX_VALID_ADDR = 1;
    parameter SECTOR1_START_ADDR = 1;
    parameter SECTOR1_END_ADDR = 1;
    parameter SECTOR2_START_ADDR = 1;
    parameter SECTOR2_END_ADDR = 1;
    parameter SECTOR3_START_ADDR = 1;
    parameter SECTOR3_END_ADDR = 1;
    parameter SECTOR4_START_ADDR = 1;
    parameter SECTOR4_END_ADDR = 1;
    parameter SECTOR5_START_ADDR = 1;
    parameter SECTOR5_END_ADDR = 1;
    parameter SECTOR_READ_PROTECTION_MODE = 5'b11111;
    parameter SECTOR1_MAP = 1;
    parameter SECTOR2_MAP = 1;
    parameter SECTOR3_MAP = 1;
    parameter SECTOR4_MAP = 1;
    parameter SECTOR5_MAP = 1;
    parameter ADDR_RANGE1_END_ADDR = 1;
    parameter ADDR_RANGE2_END_ADDR = 1;
    parameter ADDR_RANGE1_OFFSET = 1;
    parameter ADDR_RANGE2_OFFSET = 1;
    parameter ADDR_RANGE3_OFFSET = 1;

    localparam [1:0]    ERASE_ST_IDLE = 0,
                        ERASE_ST_PENDING = 1,
                        ERASE_ST_BUSY = 2;

    localparam [1:0]    STATUS_IDLE = 0,
                        STATUS_BUSY_ERASE = 1,
                        STATUS_BUSY_WRITE = 2,
                        STATUS_BUSY_READ = 3;
    
    // State 0~4 is common for both RW and read only mode. State 5~8 is only needed in RW mode.
    localparam [3:0]    OP_STATE_IDLE = 0,
                        OP_STATE_ADDR = 1,
                        OP_STATE_READ_SHIFT = 2,
                        OP_STATE_READ_DATA = 3,
                        OP_STATE_CLEAR = 4,
                        OP_STATE_WRITE = 5,
                        OP_STATE_WAIT_BUSY = 6,
                        OP_STATE_WAIT_DONE = 7,
                        OP_STATE_RESET = 8;

    // To/From System
    input clock;
    input reset_n;
    
    // To/From Flash IP interface
    input flash_busy;
    input flash_se_pass;
    input flash_sp_pass;
    input flash_osc;
    input [DATA_WIDTH-1:0] flash_drdout;
    output flash_xe_ye;
    output flash_se;
    output flash_arclk;
    output flash_arshft;
    output flash_drclk;
    output flash_drshft;
    output flash_drdin;
    output flash_nprogram;
    output flash_nerase;
    output [FLASH_ADDR_WIDTH-1:0] flash_ardin;
        
    // To/From Avalon_MM data slave interface
    input avmm_read;
    input avmm_write;
    input [AVMM_DATA_ADDR_WIDTH-1:0] avmm_addr;
    input avmm_writedata;
    input [AVMM_DATA_BURSTCOUNT_WIDTH-1:0] avmm_burstcount;
    output avmm_waitrequest;
    output avmm_readdatavalid;
    output avmm_readdata;
        
    // To/From Avalon_MM csr slave interface
    input [31:0] csr_control;
    output [9:0] csr_status;

    reg reset_n_reg1;
    reg reset_n_reg2;
    reg flash_busy_reg;
    reg flash_busy_clear_reg;
    reg flash_addr_neg_reg;
    reg flash_drdin_neg_reg;
    reg flash_drdout_neg_reg;
    reg [AVMM_DATA_BURSTCOUNT_WIDTH-1:0] cur_burstcount;
    reg [1:0] csr_status_busy;
    reg csr_status_e_pass;
    reg csr_status_w_pass;
    reg csr_status_r_pass;

    reg [3:0] op_state;
    reg op_wait;
    reg op_wait_neg_reg;
    reg op_count_start;
    reg [FLASH_ADDR_WIDTH-1:0] op_addr;
    reg op_wrap_back_addr;
    reg op_range2_addr;
    reg op_range3_addr;
    reg op_illegal_write_addr;
    reg op_scan_busy;
    
    reg arclk_en;
    reg enable_arclk_neg_reg;
    reg enable_arclk_neg_pos_reg;
    reg enable_drclk_neg_reg;
    reg enable_drclk_neg_pos_reg;
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

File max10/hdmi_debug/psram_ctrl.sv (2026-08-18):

// Controller PSRAM with SPI8 interface.
// Starts us and allows access to a 32 Mbyte sram. (16M x 16)

module psram_ctrl(
		// System
		
		input  logic	clk,
		input  logic 	clk4,
		input  logic	reset,

		// Psram spi8 interface
		// Run on Clk4. Wire up to pads (registered)
		output logic [7:0] 	spi_data_out,
		output logic   		spi_data_oe,
		output logic [1:0]   spi_le_out, // match delay
		input  logic [7:0] 	spi_data_in,
		input  logic [1:0]	spi_le_in, // match IO registering
		output logic 			spi_clk,
		output logic 			spi_cs,
		output logic 			spi_rwds_out,
		output logic 			spi_rwds_oe,
		input	 logic 			spi_rwds_in,

		// Status
		output logic			psram_ready,	// Indicates control is ready to accept requests
		
		// AXI4 R/W port
		// Write Data
		input	 logic [15:0]	wdata,
		input	 logic 			wvalid,	// assumed 1, non blocking, data is available
		output logic 			wready,
		// Write Addr
		input	 logic [24:0]	awaddr,
		input	 logic [7:0]	awlen,	// assumed 8
		input	 logic 			awvalid, 
		output logic 			awready,
		// Write Response
		input	 logic 			bready,	// Assume 1, non blocking
		output logic			bvalid,
		output logic	[1:0]	bresp,
		// Read Addr port 0
		input	 logic [24:0]	araddr0,
		input	 logic [7:0] 	arlen0,	// assumed 4, or 32
		input	 logic 			arvalid0,	
		output logic 			arready0,
		// Read Addr port 1
		input	 logic [24:0]	araddr1,
		input	 logic [7:0] 	arlen1,	// assumed 4, or 32
		input	 logic 			arvalid1,	
		output logic 			arready1,
		// Read Data
		output logic [17:0]	rdata,   // {2{ rwds, data[7:0}}}
		output logic 			rvalid,
		input	 logic 		   rready // Assumed 1, non blocking
		);
	
	// Store clocked commands;
	//     CMD  SIG State phase Nib  (input)
	logic [0:4][0:8][0:24][0:3][3:0] cmds;
	// Command shift registers
	//     CMD State
	logic [0:4][0:43] cmd_sreg, cmd_sreg_d;
	
	// Anded command reg and command bits, ready for Reduction OR
	//     SIG   Nib phase CMD State   (output)
	logic  [0:8][3:0][0:3][0:4][0:24] gated_cmds;
	logic  [0:8][3:0][0:3]            cmds_reg;
	logic  [0:8][3:0]						 cmds_x4;
	
	// AXI address registers
	logic [24:0] awaddr_reg;
	logic [24:0] araddr_reg;
	
	// Commands
	parameter CRESET = 0;
	parameter CRDID7 = 1;
	parameter CWRLAT = 2;
	parameter CRDMEM = 3;
	parameter CWRMEM = 4;
	// Wave Index
	parameter ICLK = 0; // Clock generation
	parameter ICS  = 1; // Chip select generation (note inversion
	parameter IDOE = 2; // Data Bus output enable
	parameter IDQH = 3; // Input write data (high mibble)
	parameter IDQL = 4; // Input write data (low mibble)
	parameter ILE =  5; // { LE1, LE0 } latch enable signals for propagation
	parameter ISOE = 6; // { RWDS, OE } for rwds signal
	parameter ILST = 7; // Last 
	parameter IRDY = 8; // Input write data ready signal
	
	// Re-arrange Read address for command insertion
	logic [7:0][3:0] ar;  // 8 byte aligned read address
	logic [15:0] arh0, arl0, arh1, arl1;
	assign ar   = { 7'h00, araddr_reg[24:3], 3'b000 };  // 8 byte aligned read address
	assign arh0 = { ar[7], ar[7], ar[5], ar[5] };
	assign arl0 = { ar[6], ar[6], ar[4], ar[4] };
	assign arh1 = { ar[3], ar[3], ar[1], ar[1] };
	assign arl1 = { ar[2], ar[2], ar[0], ar[0] };
	
	// Re-arrange write address for command insertion
	logic [7:0][3:0] aw;
	logic [15:0] awh0, awl0, awh1, awl1;
	assign aw   = { 7'h00, awaddr_reg[24:4], 4'b0000 };  // 16 byte aligned write address	
	assign awh0 = { aw[7], aw[7], aw[5], aw[5] };
	assign awl0 = { aw[6], aw[6], aw[4], aw[4] };
	assign awh1 = { aw[3], aw[3], aw[1], aw[1] };
	assign awl1 = { aw[2], aw[2], aw[0], aw[0] };	
	
	// Re-arrange write data for command insertion
	logic [15:0] d, dh, dl;
	logic [15:0] wdata_reg;
	always @(posedge clk)
		wdata_reg <= wdata;
	assign d = wdata_reg;
	assign dh = { {2{d[15:12]}}, {2{d[7:4]}} };
	assign dl = { {2{d[11: 8]}}, {2{d[3:0]}} };   
	
	///////////////////////
	/// Command Chains
	///////////////////////
	
	always_comb begin : _command_decode
		// default inputs to zero
		cmds = 0; 
		//   						      | Reset_En        | Soft Reset and then delay
		//   RESET   	            | CMD    | CS     | CMD    |
		//                         | 0      | 1      | 2      |
		cmds[CRESET][ICLK][0:02] = {16'h0110,16'h0000,16'h0110};
		cmds[CRESET][ICS ][0:02] = {16'h1111,16'h0000,16'h1111};
		cmds[CRESET][IDOE][0:02] = {16'h1111,16'h0000,16'h1111};
		cmds[CRESET][IDQH][0:02] = {16'h6666,16'h0000,16'h9999};
		cmds[CRESET][IDQL][0:02] = {16'h6666,16'h0000,16'h9999};
		cmds[CRESET][ILE ][0:02] = 0;
		cmds[CRESET][ISOE][0:02] = 0;
		cmds[CRESET][ILST][0:02] = {16'h0000,16'h0000,16'h1111};
		cmds[CRESET][IRDY][0:02] = 0;
		//                         | Read ID Lat=7
		//   READ ID	            | CMD    | A0     | A1     | L1     | L2     | L3     | L4     | L5     | L6     | L7     | L1     | L2     | L3     | L4     | L5     | L6     | L7     | Extra  | ID0    | ID1    | del    |
		//                         | 0      | 1      | 2      | 3      | 4      | 5      | 6      | 7      | 8      | 9      | 10     | 11     | 12     | 13     | 14     | 15     | 16     | 17     | 18     | 19     | 20     |
		cmds[CRDID7][ICLK][0:20] = {16'h0110,16'h0110,16'h0110,16'h0110,16'h0110,16'h0110,16'h0110,16'h0110,16'h0110,16'h0110,16'h0110,16'h0110,16'h0110,16'h0110,16'h0110,16'h0110,16'h0110,16'h0110,16'h0110,16'h0110,16'h0000};
		cmds[CRDID7][ICS ][0:20] = {16'h1111,16'h1111,16'h1111,16'h1111,16'h1111,16'h1111,16'h1111,16'h1111,16'h1111,16'h1111,16'h1111,16'h1111,16'h1111,16'h1111,16'h1111,16'h1111,16'h1111,16'h1111,16'h1111,16'h1111,16'h0000};
		cmds[CRDID7][IDOE][0:20] = {16'h1111,16'h1111,16'h1111,16'h0000,16'h0000,16'h0000,16'h0000,16'h0000,16'h0000,16'h0000,16'h0000,16'h0000,16'h0000,16'h0000,16'h0000,16'h0000,16'h0000,16'h0000,16'h0000,16'h0000,16'h0000};
		cmds[CRDID7][IDQH][0:20] = {16'h9999,16'h0000,16'h0000,16'h0000,16'h0000,16'h0000,16'h0000,16'h0000,16'h0000,16'h0000,16'h0000,16'h0000,16'h0000,16'h0000,16'h0000,16'h0000,16'h0000,16'h0000,16'h0000,16'h0000,16'h0000};
		cmds[CRDID7][IDQL][0:20] = {16'hFFFF,16'h0000,16'h0000,16'h0000,16'h0000,16'h0000,16'h0000,16'h0000,16'h0000,16'h0000,16'h0000,16'h0000,16'h0000,16'h0000,16'h0000,16'h0000,16'h0000,16'h0000,16'h0000,16'h0000,16'h0000};
		cmds[CRDID7][ILE ][0:20] = {16'h0000,16'h0000,16'h0000,16'h0000,16'h0000,16'h0000,16'h0000,16'h0000,16'h0000,16'h0000,16'h0000,16'h0000,16'h0000,16'h0000,16'h0000,16'h0000,16'h0000,16'h0000,16'h0010,16'h2010,16'h2000};
		cmds[CRDID7][ISOE][0:20] = 0;
		cmds[CRDID7][ILST][0:20] = {16'h0000,16'h0000,16'h0000,16'h0000,16'h0000,16'h0000,16'h0000,16'h0000,16'h0000,16'h0000,16'h0000,16'h0000,16'h0000,16'h0000,16'h0000,16'h0000,16'h0000,16'h0000,16'h0000,16'h0000,16'h1111};
		cmds[CRDID7][IRDY][0:20] = 0;
		//                         | WriteEn|        | Write CR0 = 8FEF to give LAT=3    |        | WriteEn (again!)
		//   WRITE Latency 3       | CMD    | CS     | CMD    | A0     | A1     | CR     | CS     | CMD
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

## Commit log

2026-08-16 V0.1 kicad schematic components and pcb floorplanning.
    [dev_board.kicad_pcb, dev_board.kicad_sch]
2026-08-17 V0.2 pcb placement, good enough to proceed/.
    [dev_board.kicad_pcb, dev_board.kicad_sch]
2026-08-17 TT framework for ldt_core.sv
2026-08-17 Dev board, clipped wings, side profile.
2026-08-18 Max10 starting framework brought over
    [font_5x7_gen.xlsx]
2026-08-18 lo-tec MXC400 accel interface master, 100Hz poll.
2026-08-19 Basic tb.v integraiton and i2c waves-ish
2026-08-19 accel interfeace running and plotting vga on max10 fpga. Next connect real accelerometer.
2026-08-19 Bidir I/O for accel i2c. ready for hw accel bring-up
2026-08-19 fixup i2c stuff
2026-08-20 Observed xyz accelleration on hdmi scope. A few tb monitoring issues need attention, but function seens in ldt core.
    [deploy_chip.sv]
2026-08-21 full cycle sims with short GL
    [test.py]
2026-08-21 Connected simulated accel with button thrust
2026-08-23 V0.3 schematic complete, footprints, 3d mods, prelim plancement. Ready for review then routing.
    [dev_board.kicad_pcb, dev_board.kicad_sch]
2026-08-24 Detailed BOM update, Stocked DPNs added. $16cad (or $26 with emulator connectors)
    [dev_board.csv, dev_board.kicad_sch]
2026-08-24 Add pdf of v0.3 schematic for review
2026-08-26 Added Fram in soic-8 as flight recorder for validation flights
    [dev_board.csv, dev_board.kicad_pcb, dev_board.kicad_sch]
2026-08-28 pcb v0.5 added fram, and isp hdr, first place and route, assigned chip i/o to match routing.
    [dev_board.csv, dev_board.kicad_pcb, dev_board.kicad_sch]
2026-08-28 Added forge 1k project and wrapper using pcb optimized I/O. Same utilzation as the 1x1 TT.
2026-08-28 Accel tool to test device via i2c from pi
2026-08-30 PCB v0.7 schem, pdf, pcb, gerbs
    [dev_board.kicad_pcb, dev_board.kicad_sch]
2026-08-31 Update to v0.8 pcb, sch, bom, gerbs, pdf. Tapeout candidate?
    [dev_board.csv, dev_board.kicad_pcb, dev_board.kicad_sch]
2026-09-01 i2c test tools on pi5
2026-09-03 cleanup i2c slave acks during fram write
2026-09-03 double buffer I2c message log before rendering on HDMI display for stability - nice.
    [deploy_chip.sv]
2026-09-03 Fix cont_en polarity, start recording only after continuity detected
    [test.py]
2026-09-03 Add audio tones and set max10 test timer switches for 5 sec delay.
2026-09-03 Testbench fix to match active low cont en
    [test.py]
2026-09-05 Connect sim to I2c bus to external Accel/Fram, and external cont_sense (button) for running system
2026-09-05 setup push button for cont sense input (complemented)
2026-09-06 Quick 5 sec thrust plot util to dump flight recorder
2026-09-07 Added frame blank check util
2026-09-07 Added nacks to i2c monitor output.
2026-09-08 reset meta stability flops.
    [deploy_chip.sv]
2026-09-08 Added per cycle I2c bus reset
2026-09-08 change intentionally unaddressable i2c device to EE and remove 'bus reset'
2026-09-09 Handle corner case during plotting
2026-09-13 Hold I2c sda constant for bit time.
2026-09-16 Invert ldt_core cont_en output
    [test.py]
2026-09-17 Dev board v0.8 schematic post-bringup ECOs: add pfet,zener,pnp 30v disconnect, cont en npn driver, updated reistor values.
    [dev_board_eco.kicad_sch]
2026-09-21 Add dev board photo
2026-09-21 V0.9 pcb in progress.
    [dev_board.csv, dev_board.kicad_pcb, dev_board.kicad_sch]
2026-09-22 V0.99 pcb dev board schem, pcb, bom, pcba
    [dev_board.csv, dev_board.kicad_pcb, dev_board.kicad_sch]
2026-09-22 pcba assembly files
    [XS_LDT_DB_v0.99_bom.csv, XS_LDT_DB_v0.99_designators.csv, XS_LDT_DB_v0.99_positions.csv]
2026-09-22 Fixup LSCS part num
    [dev_board.csv, dev_board.kicad_sch]
2026-09-24 Stripped down the dev board for a PCBA product quotes
    [XS-LDT-PB-V1_bom.csv, XS-LDT-PB-V1_designators.csv, prod_board.kicad_pcb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]
2026-09-24 prod bom (LCSC and DPN numbers)
    [prod_board.csv]
2026-10-03 Flight test #2: timer, deployment all good, except flight log is all zeros, except 1st 2 words.
2026-10-05 fix this up for more precise filter 23 of 25.
2026-10-07 Feature: Status Led follows speaker tones.
2026-10-08 Pcb PB updated to fix missing net
    [XS-LDT-PB-V1.1_bom.csv, XS-LDT-PB-V1.1_designators.csv, XS-LDT-PB-V1.1_positions.csv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]
